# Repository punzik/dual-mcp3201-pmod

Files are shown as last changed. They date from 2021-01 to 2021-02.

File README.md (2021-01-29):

# Модуль PMOD с двумя АЦП MCP3201

На модуле установлены два АЦП __MCP3201__ (интерфейс SPI), источник опорного
напряжения __REF3030__ с напряжением 3.0В и антиалиасинговые фильтры с полосой
10Гц-10кГц. Распиновка разъема PMOD стандартная:

| Pin | Signal | Dir. |
|-----|---|---|
| 1 | SS_N_L | IN |
| 2 | -- | |
| 3 | MISO_L | OUT  |
| 4 | SCLK_L | IN |
| 5 | GND | |
| 6 | +3.3V  | |
| 7 | SS_N_R | IN |
| 8 | -- | |
| 9 | MISO_R | OUT  |
| 10  | SCLK_R | IN |
| 11  | GND | |
| 12  | +3.3V  | |

3D рендер платы:

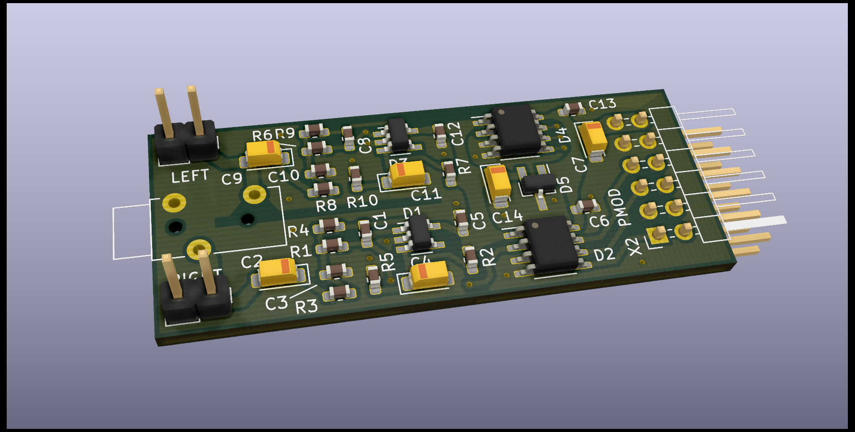
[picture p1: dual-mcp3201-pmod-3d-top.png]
3D top


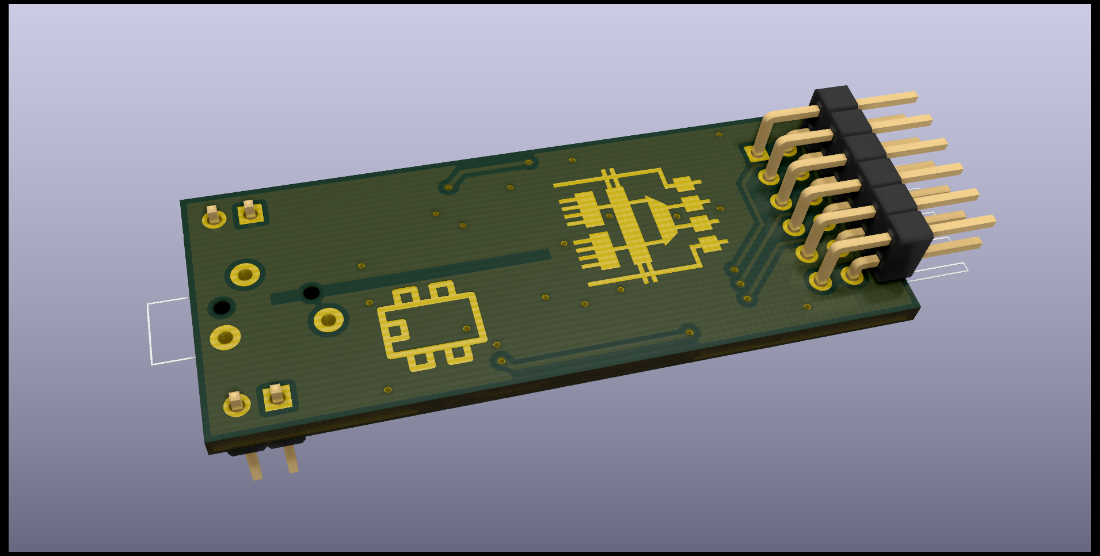
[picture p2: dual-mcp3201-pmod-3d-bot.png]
3D bot


АЧХ антиалиасинговых фильтров:

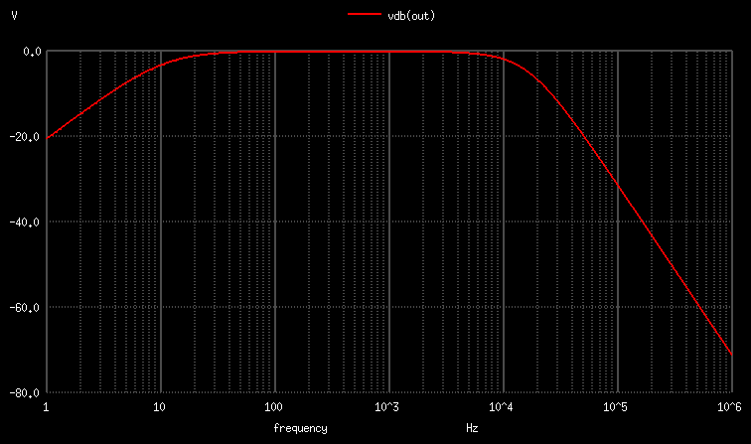
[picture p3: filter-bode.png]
Filter Bode plot


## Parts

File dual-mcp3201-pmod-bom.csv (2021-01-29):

Reference | Quantity | Value | Footprint | Datasheet | Description | Package | PartNumber | Spice_Lib_File | Spice_Model | Spice_Netlist_Enabled | Spice_Node_Sequence | Spice_Primitive | Tolerance | Type | Voltage
C1 C8 | 2 | 680p | Capacitor_SMD:C_0603_1608Metric_Pad1.05x0.95mm_HandSolder |  | SMD Ceramic Capacitor NP0 | 0603 | - |  |  |  |  |  | - | NP0 | 50V
C7 C14 | 2 | 10u | Capacitor_Tantalum_SMD:CP_EIA-3216-18_Kemet-A_Pad1.58x1.35mm_HandSolder |  | SMD Tantalum Capacitor | A-CASE | 293D106X9010A2TE3 |  |  |  |  |  | - | Tantalum | 10V
C2 C4 C9 C11 | 4 | 2.2u | Capacitor_Tantalum_SMD:CP_EIA-3216-18_Kemet-A_Pad1.58x1.35mm_HandSolder |  | SMD Tantalum Capacitor | A-CASE | 293D225X9010A2TE3 |  |  |  |  |  | - | Tantalum | 10V
C3 C10 | 2 | 2200p | Capacitor_SMD:C_0603_1608Metric_Pad1.05x0.95mm_HandSolder |  | SMD Ceramic Capacitor NP0 | 0603 | - |  |  |  |  |  | - | NP0 | 50V
C5 C6 C12 C13 | 4 | 0.1u | Capacitor_SMD:C_0603_1608Metric_Pad1.05x0.95mm_HandSolder |  | SMD Ceramic Capacitor X7R | 0603 | - |  |  |  |  |  | - | X7R | 16V
D1 D3 | 2 | LMV721M5 | Package_TO_SOT_SMD:SOT-23-5_HandSoldering |  | OpAMP | SOT-23-5 | LMV721M5 | spice/lmv721.lib | lmv721 | Y | 3 4 1 5 2 | X
D2 D4 | 2 | MCP3201BI/SN | Package_SO:SOP-8_3.76x4.96mm_P1.27mm |  | ADC | SO-8-150 | MCP3201BI/SN
D5 | 1 | REF3030 | Package_TO_SOT_SMD:SOT-23_Handsoldering |  | LDO Reference Voltage Source | SOT-23-3 | REF3030
R1 R3 R6 R8 | 4 | 6.8k | Capacitor_SMD:C_0603_1608Metric_Pad1.05x0.95mm_HandSolder |  | SMD Resistor | 0603 | - |  |  |  |  |  | 1%
R2 R4 R5 R7 R9 R10 | 6 | 9.1k | Capacitor_SMD:C_0603_1608Metric_Pad1.05x0.95mm_HandSolder |  | SMD Resistor | 0603 | - |  |  |  |  |  | 1%
X1 | 1 | AUB-13 | local:JACK_ST_AUB_13 |  | 3.5mm Stereo Audio Jack Receptacle |  | AUB-13
X2 | 1 | PMOD_PERIPH | local:PMOD_PERIPH |  | Right-angle 2.54mm pin-header |  | PLD-12R (PLD-80R)
X3 | 1 | RIGHT | Connector_PinHeader_2.54mm:PinHeader_1x02_P2.54mm_Vertical |  | 2.54mm 2-pin connector |  | PLS-2 (PLS-40)
X4 | 1 | LEFT | Connector_PinHeader_2.54mm:PinHeader_1x02_P2.54mm_Vertical |  | 2.54mm 2-pin connector |  | PLS-2 (PLS-40)

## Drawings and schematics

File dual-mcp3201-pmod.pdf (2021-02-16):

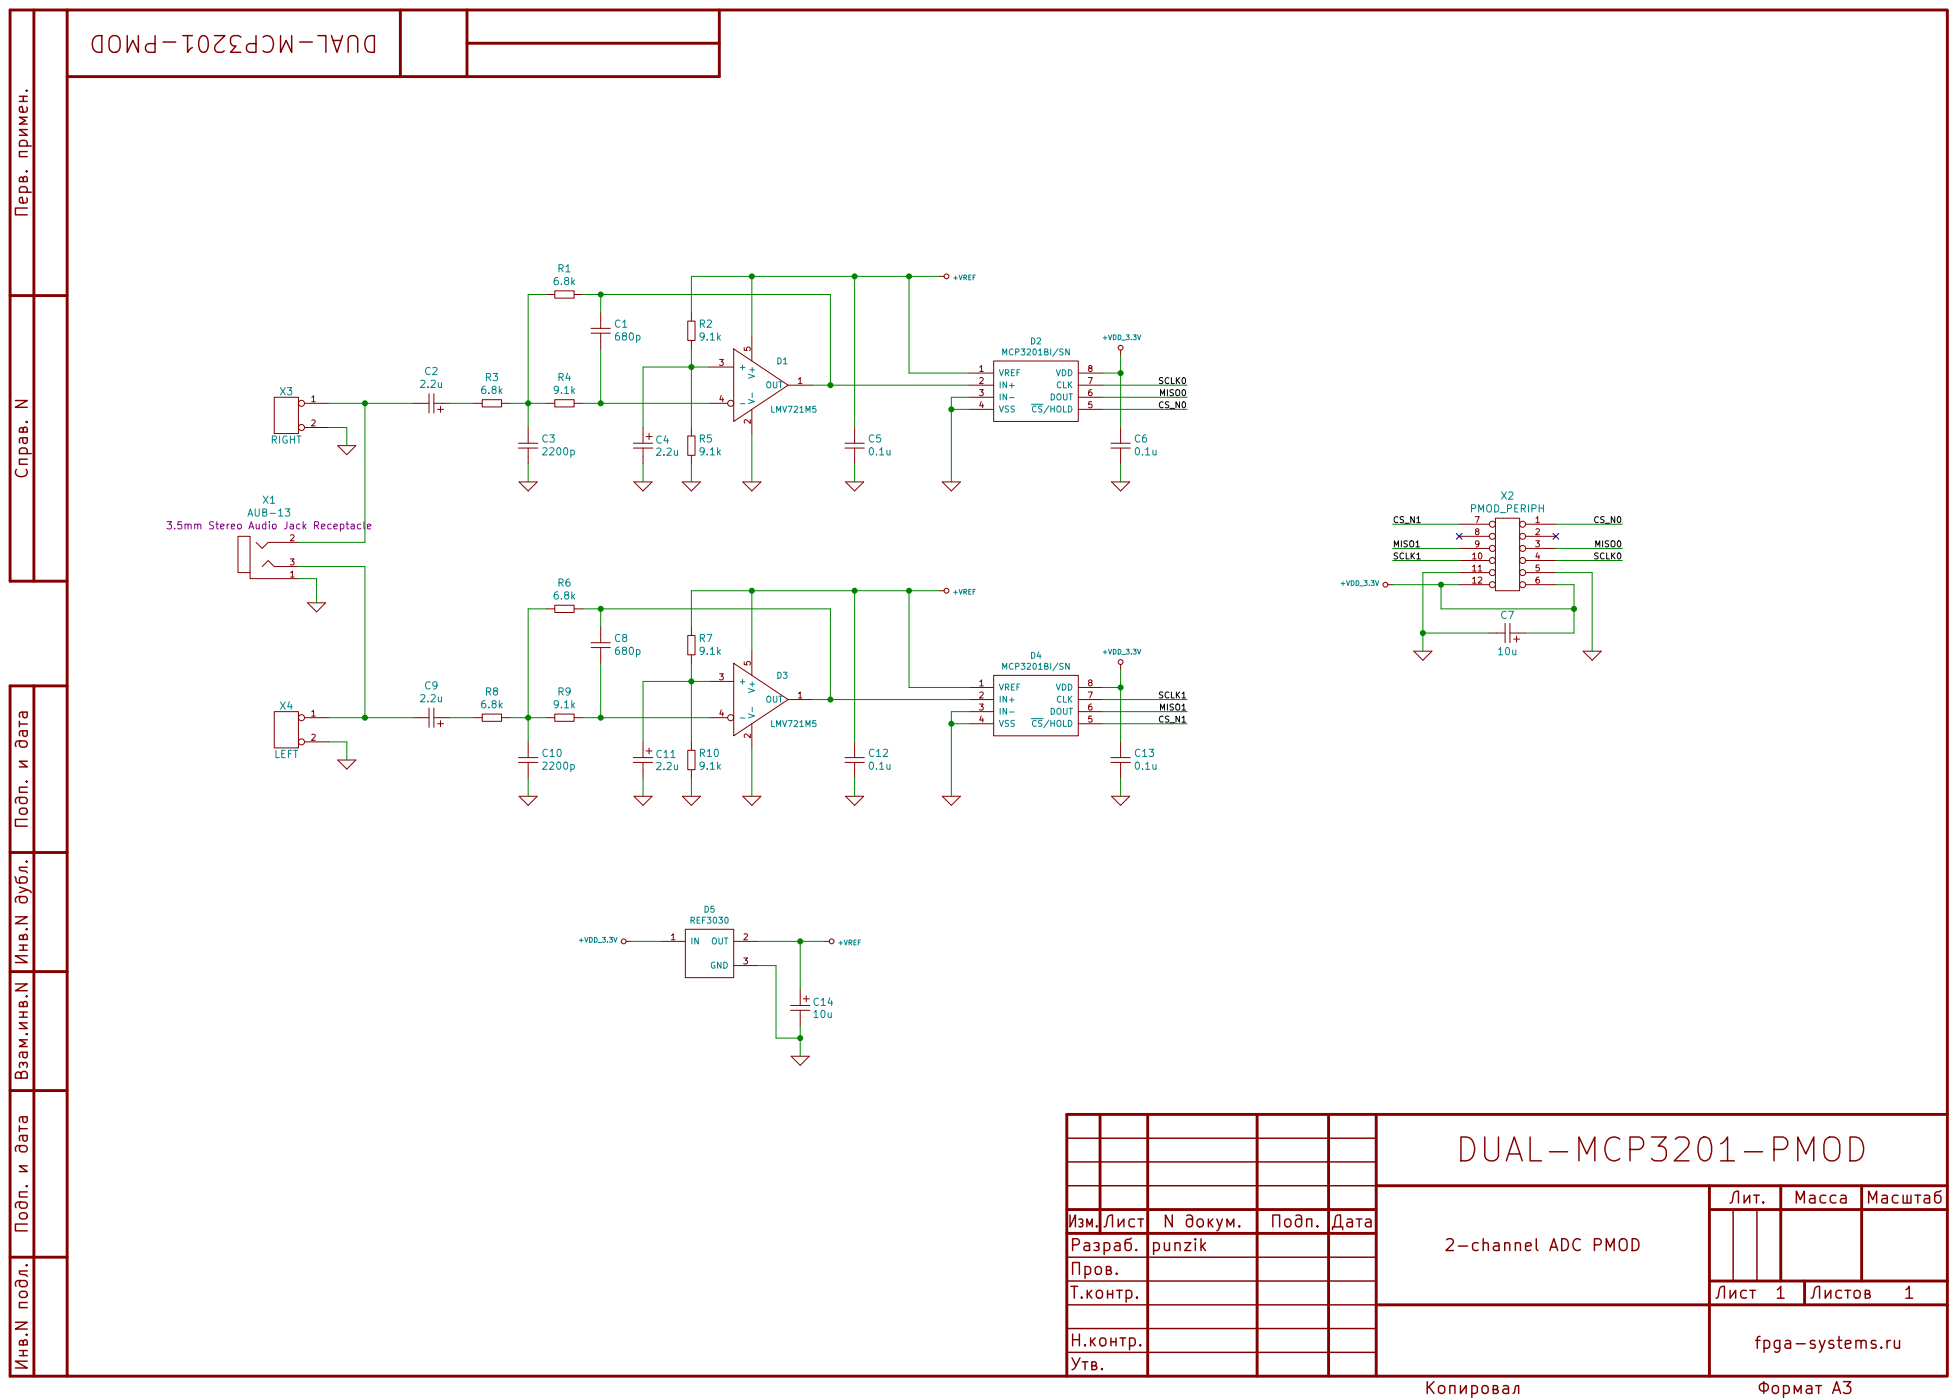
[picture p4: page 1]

3.5mm Stereo Audio Jack Receptacle

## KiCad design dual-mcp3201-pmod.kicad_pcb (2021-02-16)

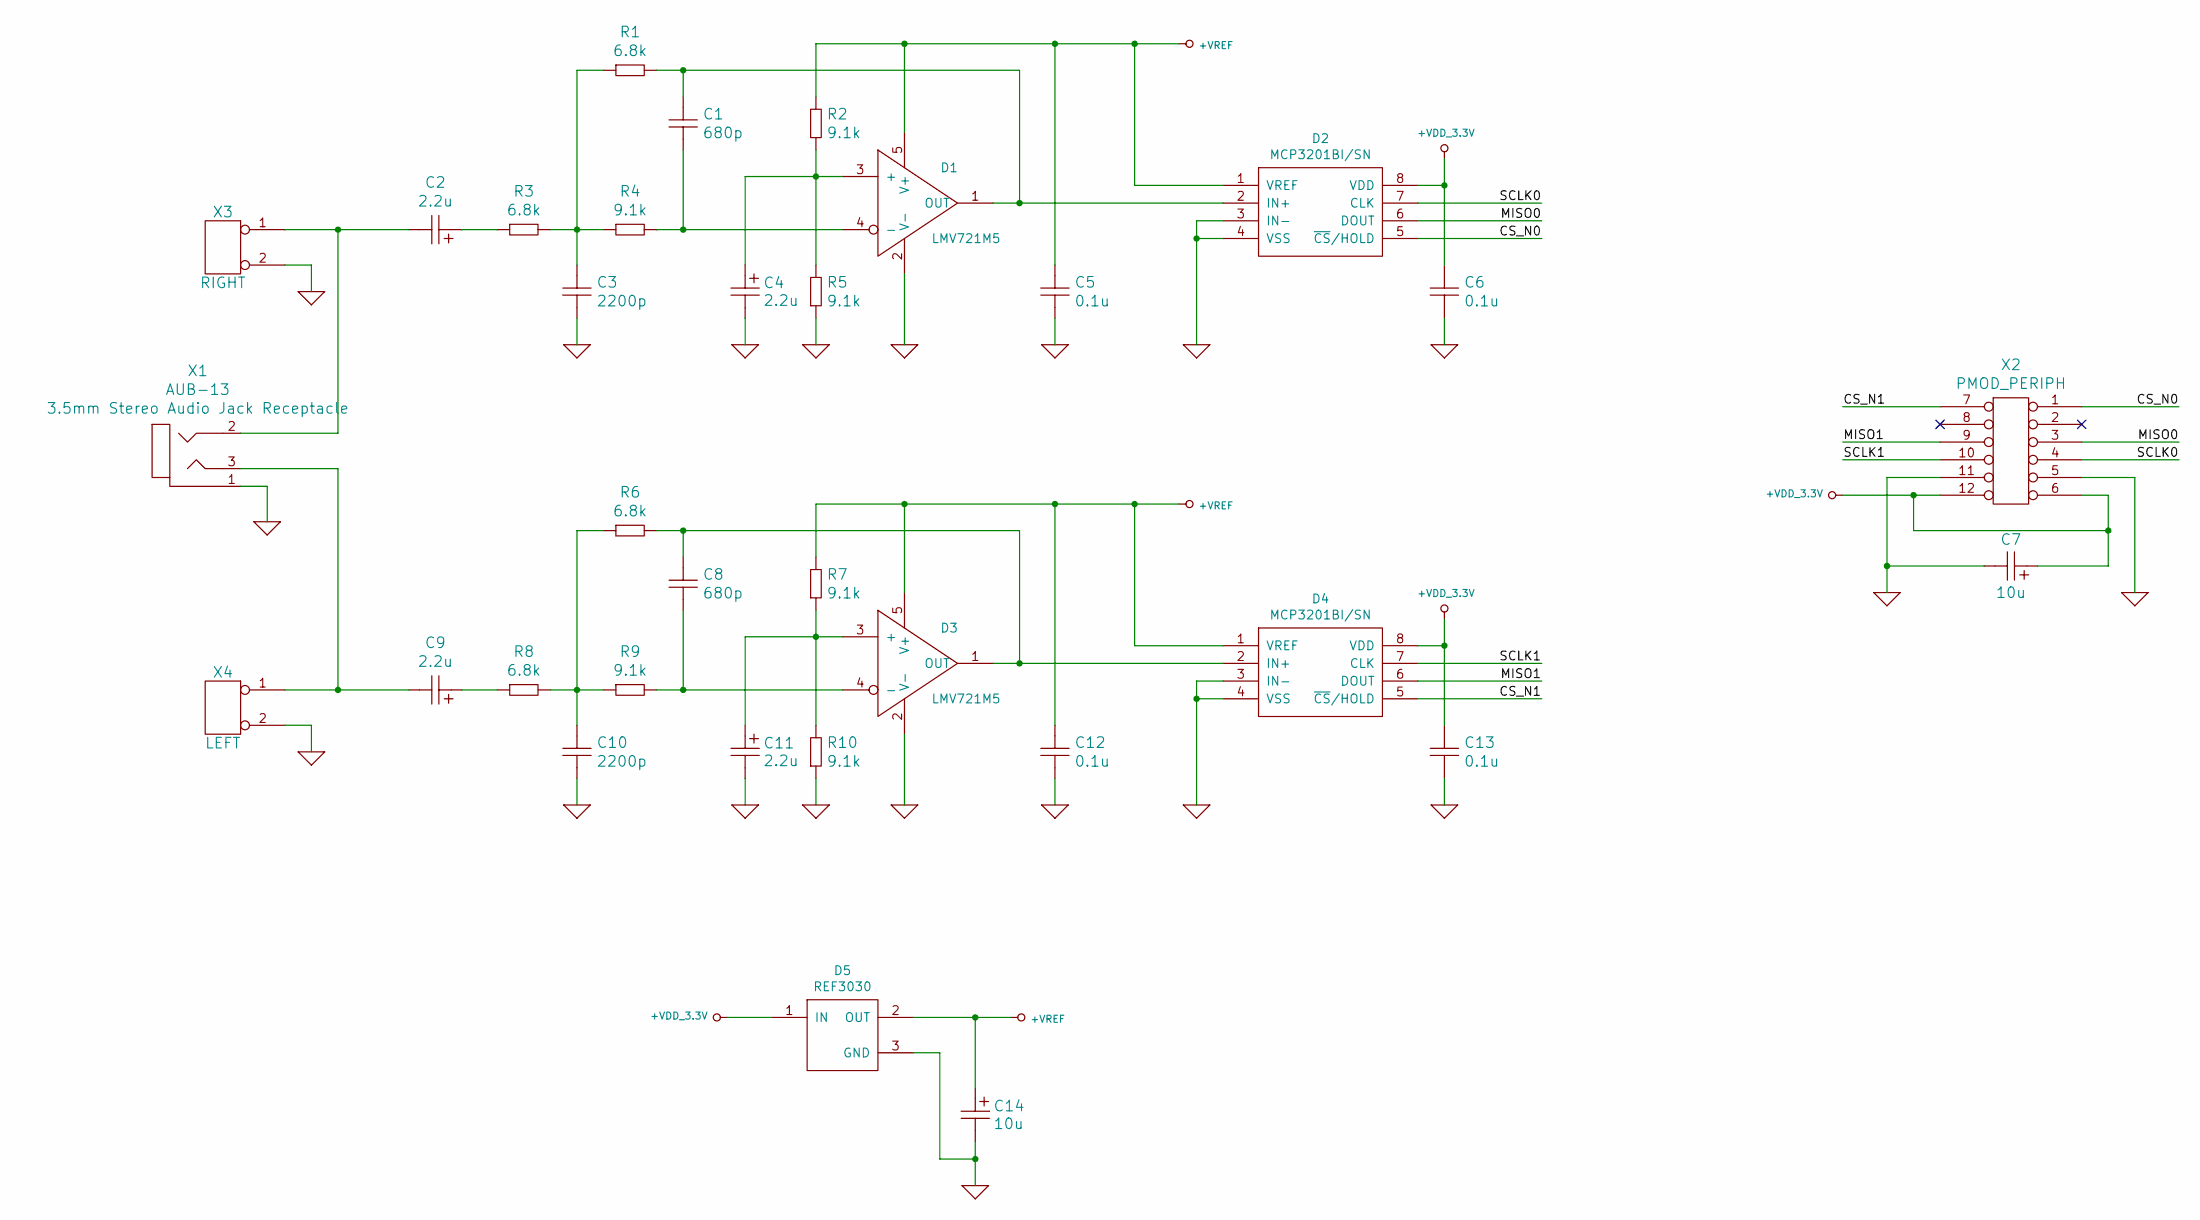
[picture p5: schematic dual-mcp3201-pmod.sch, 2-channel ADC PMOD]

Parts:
C1, C8: 680p; C_0603_1608Metric_Pad1.05x0.95mm_HandSolder; Voltage 50V
C2, C4, C9, C11: 2.2u; CP_EIA-3216-18_Kemet-A_Pad1.58x1.35mm_HandSolder; Voltage 10V; PartNumber 293D225X9010A2TE3
C3, C10: 2200p; C_0603_1608Metric_Pad1.05x0.95mm_HandSolder; Voltage 50V
C5, C6, C12, C13: 0.1u; C_0603_1608Metric_Pad1.05x0.95mm_HandSolder; Voltage 16V
C7, C14: 10u; CP_EIA-3216-18_Kemet-A_Pad1.58x1.35mm_HandSolder; Voltage 10V; PartNumber 293D106X9010A2TE3
D1, D3: LMV721M5; SOT-23-5_HandSoldering; PartNumber LMV721M5
D2, D4: MCP3201BI/SN; SOP-8_3.76x4.96mm_P1.27mm; PartNumber MCP3201BI/SN
D5: REF3030; SOT-23_Handsoldering; PartNumber REF3030
R1, R3, R6, R8: 6.8k; C_0603_1608Metric_Pad1.05x0.95mm_HandSolder; Tolerance 1%
R2, R4, R5, R7, R9, R10: 9.1k; C_0603_1608Metric_Pad1.05x0.95mm_HandSolder; Tolerance 1%
X1: AUB-13; JACK_ST_AUB_13; PartNumber AUB-13
X2: PMOD_PERIPH; PartNumber PLD-12R (PLD-80R)
X3: RIGHT; PinHeader_1x02_P2.54mm_Vertical; PartNumber PLS-2 (PLS-40)
X4: LEFT; PinHeader_1x02_P2.54mm_Vertical; PartNumber PLS-2 (PLS-40)

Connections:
+VDD_3.3V: C6.2, C7.1, C13.2, D2.8 (VDD), D4.8 (VDD), D5.1 (IN), X2.6, X2.12
+VREF: C5.2, C12.2, C14.1, D1.5 (V+), D2.1 (VREF), D3.5 (V+), D4.1 (VREF), D5.2 (OUT), R2.2, R7.2
/CS_N0: D2.5 (~CS~/HOLD), X2.1
/CS_N1: D4.5 (~CS~/HOLD), X2.7
/MISO0: D2.6 (DOUT), X2.3
/MISO1: D4.6 (DOUT), X2.9
/SCLK0: D2.7 (CLK), X2.4
/SCLK1: D4.7 (CLK), X2.10
GND: C3.1, C4.2, C5.1, C6.1, C7.2, C10.1, C11.2, C12.1, C13.1, C14.2, D1.2 (V-), D2.3 (IN-), D2.4 (VSS), D3.2 (V-), D4.3 (IN-), D4.4 (VSS), D5.3 (GND), R5.1, R10.1, X1.1, X2.5, X2.11, X3.2 (PM), X4.2 (PM)
unnamed: C1.1, D1.4 (-), R4.2
unnamed: C1.2, D1.1 (OUT), D2.2 (IN+), R1.2
unnamed: C2.1, R3.1
unnamed: C2.2, X1.2, X3.1
unnamed: C3.2, R1.1, R3.2, R4.1
unnamed: C4.1, D1.3 (+), R2.1, R5.2
unnamed: C8.1, D3.4 (-), R9.2
unnamed: C8.2, D3.1 (OUT), D4.2 (IN+), R6.2
unnamed: C9.1, R8.1
unnamed: C9.2, X1.3, X4.1
unnamed: C10.2, R6.1, R8.2, R9.1
unnamed: C11.1, D3.3 (+), R7.1, R10.2

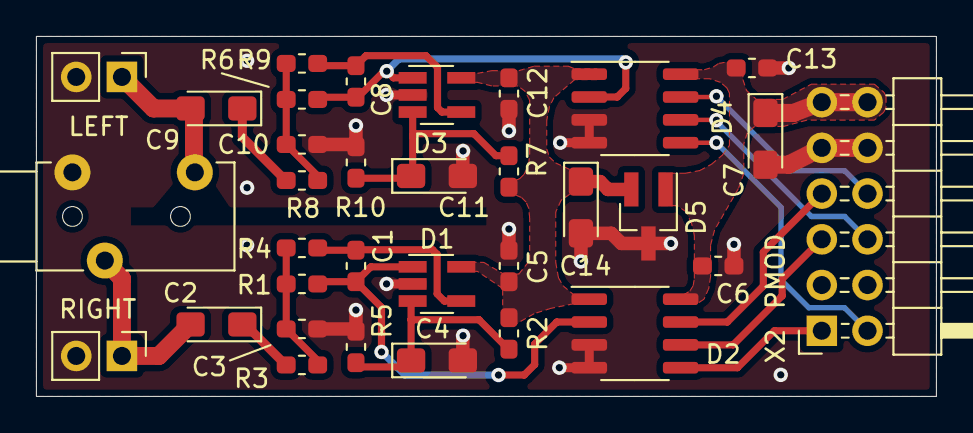
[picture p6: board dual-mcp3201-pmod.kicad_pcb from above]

Board: 2 copper layers, 50.0 x 20.0 mm, 33 parts (0 on the bottom side), 21 nets.

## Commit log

2021-01-25 Initial commit. First release
    [dual-mcp3201-pmod-B_Cu.gbr, dual-mcp3201-pmod-B_Mask.gbr, dual-mcp3201-pmod-B_Paste.gbr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]
2021-01-26 Connect flying via to ground
    [dual-mcp3201-pmod-B_Cu.gbr, dual-mcp3201-pmod-B_Mask.gbr, dual-mcp3201-pmod-B_Paste.gbr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]
2021-01-29 Change filter cut-off frequency to 10kHz
    [dual-mcp3201-pmod.sch]
2021-01-29 Update BOM
    [dual-mcp3201-pmod-bom.csv]
2021-02-16 Fix and update manufacturing files
    [dual-mcp3201-pmod-B_Cu.gbr, dual-mcp3201-pmod-B_Mask.gbr, dual-mcp3201-pmod-Dwgs_User.gbr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]
